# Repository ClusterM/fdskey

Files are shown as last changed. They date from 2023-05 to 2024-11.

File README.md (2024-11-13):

# FDSKey
An open-source, low-cost, and easy-to-build Famicom Disk System drive emulator featuring a sleek OLED display.





How you can use it:
* You can run Famicom Disk System disk images from a microSD card 
* You can dump disks using a physical FDS drive without additional hardware/cables
* You can write disks using a physical FDS drive without additional hardware/cables

Requirements:
* Famicom
* Famicom Disk System RAM adaptor
* microSD card

## How to build it
You'll need a few low-cost components.

### Circuit diagram
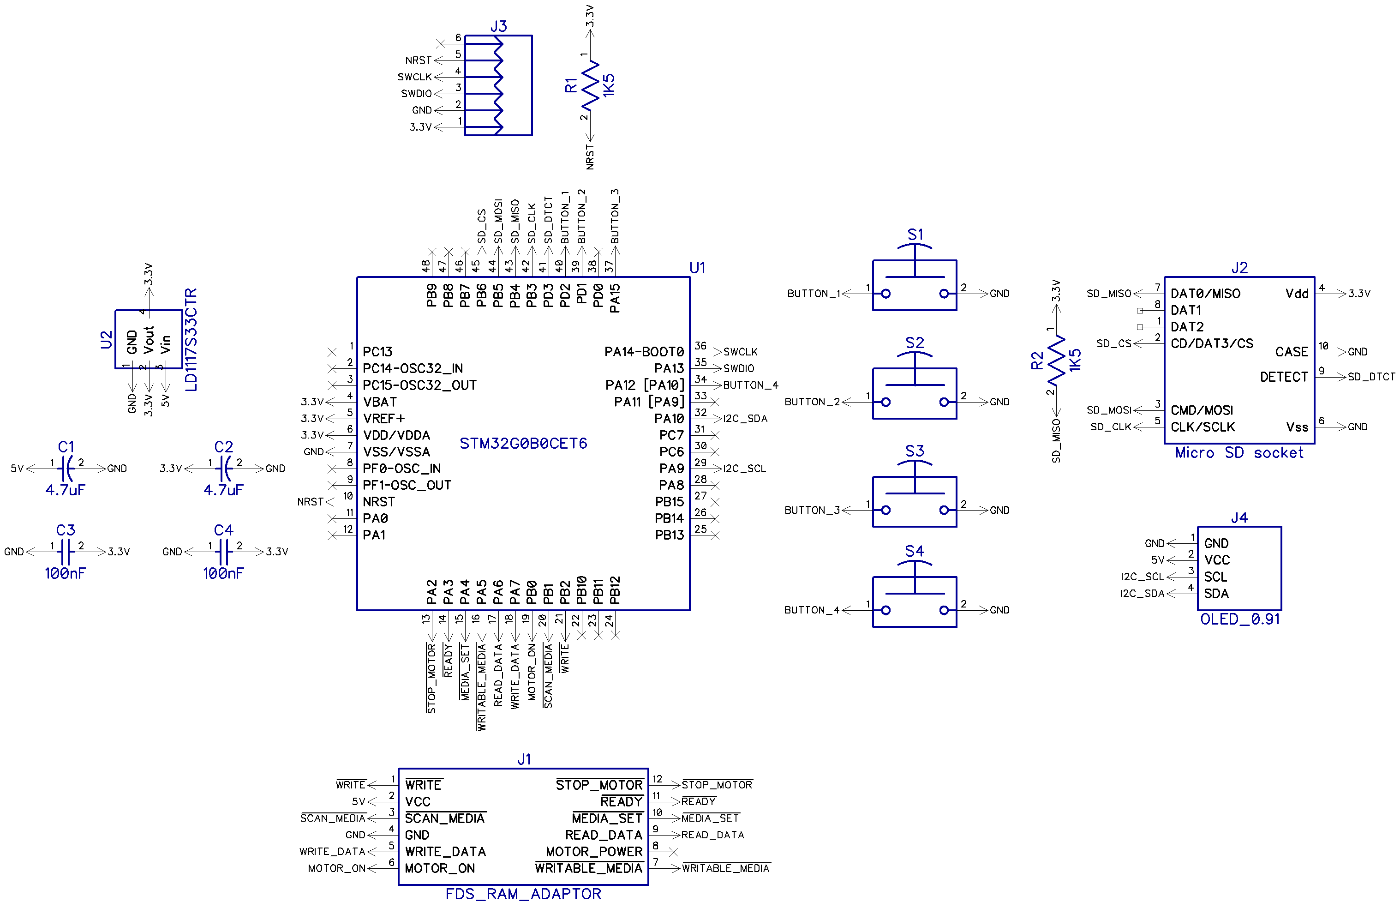
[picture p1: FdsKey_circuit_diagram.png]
Сircuit diagram


### Bill of materials
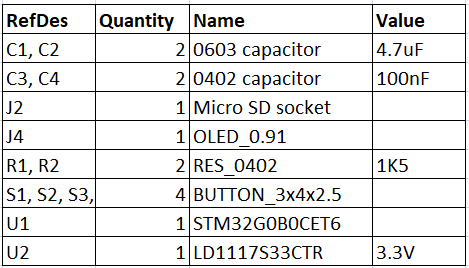
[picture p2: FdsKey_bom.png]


### Components
1. **PCB**



The PCB is designed in the [DipTrace](https://diptrace.com/) software.

You can have it produced at any PCB factory (e.g. [jlcpcb.com](https://jlcpcb.com) or [PCBWay](https://pcbway.com/)) using [gerber files](PCB_gerbers). PCB properties:
* PCB thickness: 1.6mm
* Gold fingers are recommended

2. **STM32G0B0CET (or any STM32G0B0CETxxx) microcontroller**

STM32G0B0CET

You can easily find it on [mouser.com](https://www.mouser.com/c/?q=STM32G0B0CET) or [taobao.com](https://s.taobao.com/search?q=STM32G0B0CET).

3. **OLED display module**

OLED display

OLED display

It's a very popular OLED display, search for **SSD1306 0.91-inch OLED 128x32 4-pin** on [aliexpress.com](https://aliexpress.com), [ebay.com](https://ebay.com), [amazon.com](https://amazon.com) or [taobao.com](https://taobao.com). These displays are available in different colors: blue, white and yellow, you can select the one you prefer.

Solder it like this:



It's recommended to put something soft under the display on the right side.

**WARNING**: some unscrupulous sellers may sell you used, burned-in displays.

4. **microSD card socket (push-push, 8-pin + card detect pin = 9-pin)**

microSD card socket

microSD card socket

It's a very popular push-push socket, they can be found on [aliexpress.com](https://aliexpdress.com). Also, you can search for **112J-TDAR-R01** model but there are many compatible models with other names. You can always modify the PCB to accommodate a different socket model.

5. **LD1117S33 stabilizer**

LD1117S33

You can buy it in any electronic components store.

6. **Four SMD buttons**

SMD button

Search for **3X4X2.5H SMD** buttons, they can be found on [aliexpress.com](https://aliexpress.com), [ebay.com](https://ebay.com), [amazon.com](https://amazon.com) or [taobao.com](https://taobao.com). You can also search for **434133025816** model on [mouser.com](https://www.mouser.com/c/?q=STM32G0B0CET).

7. **Resistors and capacitors**

Capacitor

You will need only a few of them:
* C1, C2 - two 4.7uF ceramic capacitors, 0603 size (higher values are not recommended)
* C3, C4 - two 100nF ceramic capacitors, 0402 size (0603 will be fine too)
* R1, R2 - two 1.5K resistors, 0402 size (0603 will be fine too), actually you can also use any values from 1K to 10K

You can buy them in any electronic components store.

8. **Plastic case**

Case

You can print plastic case with a 3D printer. You can find .stl files in the [case_3d_models](case_3d_models) directory. There are two types of models:
* [For FDM 3D printers](case_3d_models/fdm) - can be printed on a affordable home 3D printer, the bottom and top parts of the case must be glued together
* [For MJF 3D printers](case_3d_models/mjf) (recommended) - for industrial 3D printing, you can order it from a manufacturing service (e.g. [jlcpcb.com](https://jlcpcb.com)), this version features latches



What does it look like when everything is assembled:


## Flashing the firmware
There are five TH pads (actually 6 but 1 is unused) on the PCB to connect a ST-Link (or clone) programmer: GND, VCC, SWD, SWCLK, and NRST. Use [**STM32CubeProg**](https://www.st.com/en/development-tools/stm32cubeprog.html) software (Win/Linux/Mac) to write the bootloader and the firmware. Old **STM32 ST-LINK Utility** will not work, it's deprecated.

First, you need to write the bootloader - **bootloader.bin** file. Use a programmer and write it to the **0x08000000** address (start of the flash memory, default address).

Then you can put the main firmware file - **FdsKey.bin** on your SD card (FAT/FAT32/exFAT formatted) and hold all four buttons on power-on, e.g. connect FDSKey to RAM adaptor, hold buttons and turn a Famicom on. You can use the same method to update the main firmware in the future without additional hardware. You can also use a programmer and write it to the **0x08020000** address.

You can write the bootloader and the firmware at once using the STM32CubeProg CLI tool:

`STM32_Programmer_CLI.exe -c port=SWD --erase all --download bootloader.bin 0x08000000 --download fdskey.bin 0x08020000`

After the first boot, press and hold the **left** button on the main menu screen for 3 seconds to access the service menu. There, you can select the OLED display controller type (change it if the display shows a corrupted image in "lefty mode") and check some system information.

## Device usage
Format a microSD card to FAT/FAT32/exFAT and put some .fds files on it. Insert a microSD card into a FDSKey, insert a FDSKey into a RAM Adaptor's cable instead of a physical disk drive and turn on a Famicom. You can hot plug a FDSKey when Famicom is already on too, it's ok.

Now you can navigate through the FDSKey interface using the buttons. **Left** button usually means **back**, **right** button usually means **OK** and **up**/**down** are used to select something (file, disk side, etc.) Also, you can long press the **left** button in the file browser to directly return to the main menu from a subfolder, and long press the **right** button to open the file properties menu.

FDSKey - interface flowchart

Oops, too complicated :( Let's try again...

GUI

Much better.

**WARNING**: when a game writes some data to a virtual disk (i.e., saves game progress) don't turn off your Famicom power until the updated ROM has been saved to the SD card. Wait a second for it or eject a virtual disk (**left** button). A **saving** message will be displayed, do not turn off power while this message is visible.

### Settings menu
Use **up**/**down** buttons to select a setting and **left**/**right** to change it. Setting descriptions:
* **Rewind speed**: you can select a drive operation speed as either **original** (very slow, like on a physical FDS drive, for the nostalgic ones), **fast** (where the rewind time is reduced but the virtual head position is not altered), or **turbo** (the fastest possible mode, instant head rewind).
* **Remember state**: you can select a power-on state between **none** (always start from the main menu), **browser** (open browser and select last file if browser was opened before power off), and **ROM** (start first side of the last started game emulation if ROM emulation was active before power off).
* **Saves** (since v1.1): you can select how to save game progress as either **overwrite** (just overwrite the original .fds file), **backup+overwrite** (just overwrite the original .fds file but make backup to .fds.bak file first), or **like EverDrive** (EverDrive-compatible saves format).
* **Hide non .fds files**: hide files with non .fds extension in the file browser.
* **Hide .fds extensions**: hide .fds extension in the file browser.
* **Hide hidden files**: hide hidden files and directories in the file browser.
* **Brightness**: screen brightness from 0 to 10.
* **Invert screen**: draw black on white instead of white on black.
* **Lefty mode**: rotate screen image on 180 degrees and flip buttons.
* **Screen off after**: time before automatic screen off if there is no any action (button presses, drive activity), it's recommended to use this feature to prevent OLED screen burn-in.
* **[ Save and return ]**: press **left** or **right** button on this item to return to the main menu.

### Service menu ###
You can access the service menu by holding the **left** button on the main menu screen for 3 seconds. This menu is mainly meant for developers or advanced users. There is a lot of system information and several options/functions:
* **OLED controller**: try to change it in case if "lefty mode" is not working correctly.
* **[ Format SD card ]**: use it if you want to make low-level format of your SD card. Use it with caution as you will lose all your data! Make sure to backup your data first.
* **[ Update bootloader ]**: update bootloader firmware. You need to put both **bootloader.bin** and **bootloader.bin.md5** files in the root of your SD card. Use it with caution! In case of failure (power loss during update) you will brick the device.
* **[ Save and return ]**: press **left** or **right** button on this item to return to the main menu.

## Reading and writing disks

### How to dump a physical disk to a file
You can use [DupliFDS](https://github.com/ClusterM/duplifds) to copy a physical disk to a virtual one, simply create an empty ROM. There is **Create blank disk** item in the main menu for it.
1. Put the DupliFDS ROM on the SD card.
2. Select and load the DupliFDS ROM on your SD card just like you would do with any other ROM.
3. Return to the main menu and select **Create blank disk**.
4. Enter filename for the new ROM, trailing spaces will be trimmed.
5. When DupliFDS requests a source disk, disconnect FDSKey from a RAM adaptor and connect a physical FDS drive with a game disk.
6. When DupliFDS requests a target disk, disconnect a physical drive, connect a FDSKey and select the ROM created in steps 3-4.
7. Repeat steps 5-6 until the copy operation is completed.

### How to write to a physical disk from a file
This is a reverse operation of dumping: you can use [DupliFDS](https://github.com/ClusterM/duplifds) to copy a virtual disk to a physical one. Please note that **you need to remove the copy protection from your physical drive** if it has any. In most cases, it's not such a difficult process.
1. Put the DupliFDS ROM on the SD card.
2. Select and load the DupliFDS ROM on your SD card just like you would do with any other ROM.
3. When DupliFDS requests a source disk, select the source ROM/side.
4. When DupliFDS requests a target disk, disconnect FDSKey from a RAM adaptor and connect a physical FDS drive with a blank disk.
5. Disconnect a physical FDS drive and connect the FDSKey.
6. Repeat steps 3, 4, and 5 until the copy operation is completed.

## Firmware updates
You can always download the latest version at https://github.com/ClusterM/fdskey/releases.

Also, you can download automatic interim builds at http://clusterm.github.io/fdskey/.

Remember, you can update the firmware by putting **FdsKey.bin** on your SD card and holding all four buttons on power-on.

## Twin Famicom compatibility
You can use FDSKey with Twin Famicom too. But you need a special cable. It's easy to make one.



It has a simple 12x1 dupont connector on the one side, you need to connect it to Twin Famicom's **Port C** on the back-bottom side (instead of the original cable).

Unfortunately, there is a non-standard connector on the other side of the cable. But you can use a SFC/SNES/N64/NGC AV connector:



You can find it on [aliexpress.com](https://aliexpress.com). But you need to cut a "key" - piece of plastic on this connector, or just use the FDSKey without a case.

Connection diagram:
```
           Twin Famicom Port C                   Connector for FDSKey
       (looking at rear of console)          (looking from FDSKey's side)
█████████████████████████████████████████  ████████████████████████████████
█████████████████████████████████████████  ████████████████████████████████
██                                     ██  ███  1   3   5   7   9   11  ███
██ 8  6  2  4  1  3  5  7  9  11 12 10 ██  ███  2   4   6   8   10  12  ███
█████████████████████████████████████████  \██████████████████████████████/
█████████████████████████████████████████   \████████████████████████████/

Pin meanings
+----+---+-----------------------+
| 1  | O | /write                |
| 2  | O | VCC (+5VDC)           |
| 3  | O | /scan media           |
| 4  | O | VEE (ground)          |
| 5  | O | Write data            |
| 6  | I | Motor on/battery good |
| 7  | I | /writable media       |
| 8  | - | ---                   |
| 9  | I | Read data             |
| 10 | I | /media set            |
| 11 | I | /ready                |
| 12 | O | /stop motor           |
+----+---------------------------+
```

You **must** pull-up **write data** line to **VCC** via resistor (5K-20K) if you want to save game progress, because Twin Famicom has no pull-up resistors inside it.



Also, it's recommended to pull-up **/media set** pin to **VCC** too if you want to hot plug the FDSKey. And don't forget to upgrade the FDSKey firmware to at least **v1.3**.

## Donate
* [Buy Me A Coffee](https://www.buymeacoffee.com/cluster)
* [Donation Alerts](https://www.donationalerts.com/r/clustermeerkat)
* [Boosty](https://boosty.to/cluster)

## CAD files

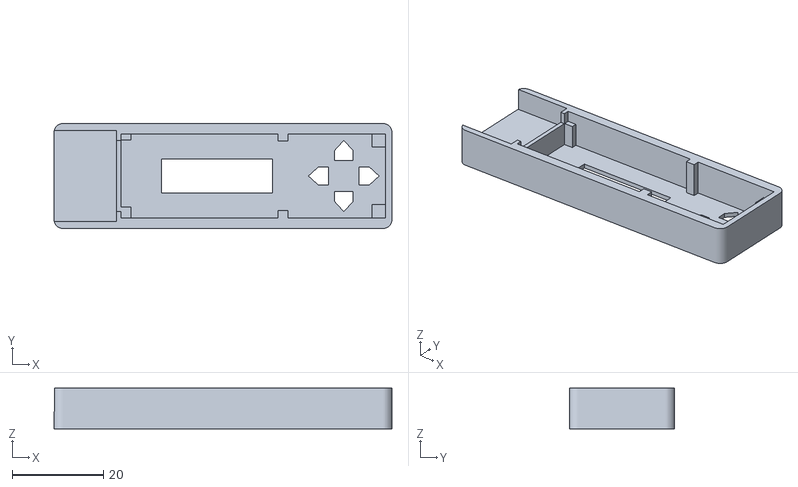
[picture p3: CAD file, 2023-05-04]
case_3d_models/fdm/top.stl
74.0 x 23.0 x 8.90

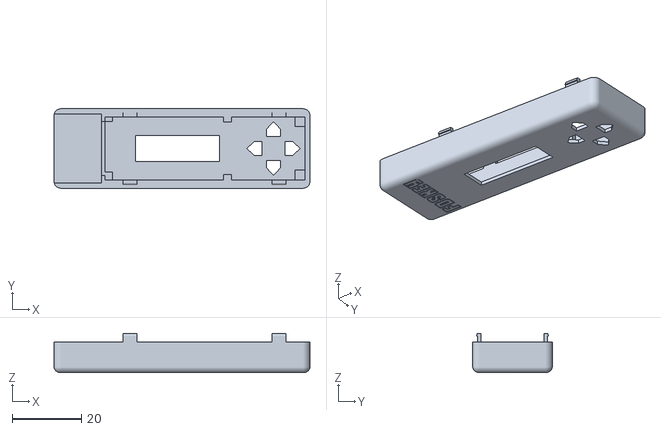
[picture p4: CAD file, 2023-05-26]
case_3d_models/mjf/top.stl
74.0 x 23.0 x 11.4

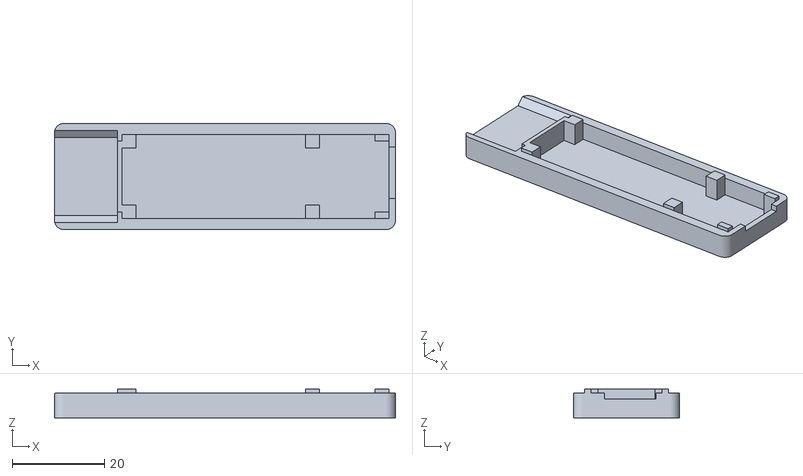
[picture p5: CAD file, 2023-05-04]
case_3d_models/fdm/bottom.stl
74.0 x 23.0 x 6.21

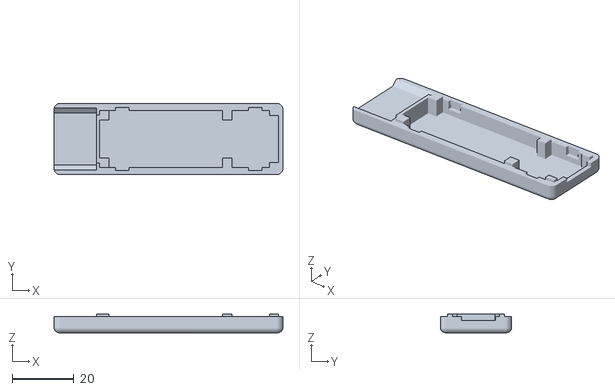
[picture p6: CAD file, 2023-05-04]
case_3d_models/mjf/bottom.stl
74.0 x 23.0 x 6.10

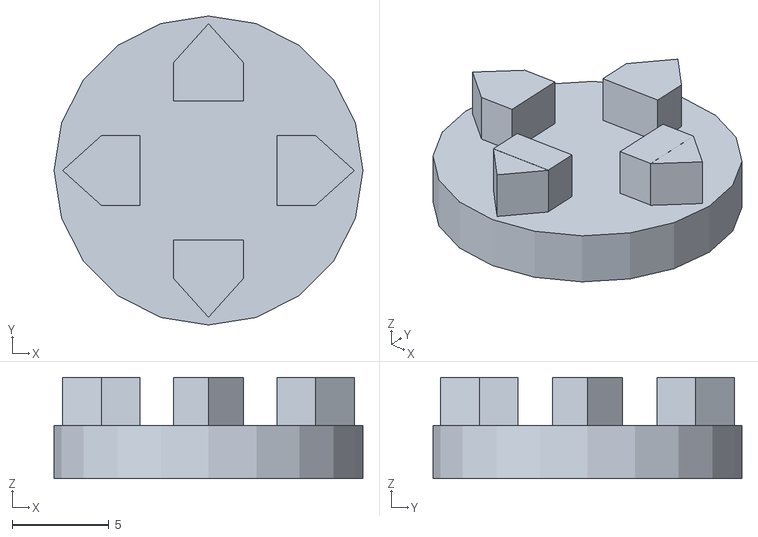
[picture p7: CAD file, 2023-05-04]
case_3d_models/fdm/buttons.stl
16.0 x 16.0 x 5.25

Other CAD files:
case_3d_models/mjf/buttons.stl

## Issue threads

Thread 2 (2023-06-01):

Broken BOM link

breyell, 2023-06-01:
Links to file in repo that doesn't exist

ClusterM, 2023-06-01:
Oops. I renamed the files but forgot to change links. Fixed. Thank you!

Closed 2023-06-01.

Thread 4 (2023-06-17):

How to flash the bootloader

donly, 2023-06-17:
Hi, there!
I read the instructions from https://github.com/ClusterM/fdskey#flashing-the-firmware, but still get stuck in connect to target:

```
Can not connect to target!
If you're trying to connect to an STM32W1xx device, please select Normal or HotPlug mode from Target->Settings menu.
If you're trying to connect to a low frequency application , please select a lower SWD Frequency mode from Target->Settings menu.
```

donly, 2023-06-17:
When using this setting, it can be connected, but it shows an unknown device, as shown in the figure
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

What kind of `Mode` and `Reset Mode` should be use.

ClusterM, 2023-06-21:
Sorry for the slow reply. Double check the connections and make sure the UC is not broken. Also? check the power. Reset mode depends on your programmer. If it has a NRST connection - use hardware reset.

donly, 2023-06-22:
Thank you ClusterM. As I'm a newbie and don't know how to use it, it's been solved now.

partlyhuman, 2023-07-27:
> Thank you ClusterM. As I'm a newbie and don't know how to use it, it's been solved now.

@donly, I too am new to STLink, I've got a clone ST-Link V2 and using the ST-Link utility. Can you elaborate for other newbies what you did to get it working?

My issues thus far:
* Only works in Mode = Hot Plug, otherwise fails to connect
* Seems to hang up if Hardware reset mode is used and NRST are connected
* "Read out protection is activated" trying to erase or program the STM32
* "the elf loader file is not accessible" when trying to program the STM32

Thank you in advance for any advice you can share! :)

donly, 2023-07-27:
Maybe your clone ST-Link doesn’t support this chip, can you try another flash tool

partlyhuman, 2023-07-27:
> Maybe your clone ST-Link doesn’t support this chip, can you try another flash tool

It's quite possible the clone ST-Link V2 usb programmer is the issue. I don't currently have any alternative... is that what your issue was?

donly, 2023-07-27:
Yes, just forget this programmer..

Closed 2023-06-20.

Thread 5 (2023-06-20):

Can work with antother STM32 microcontroler?

eduardokenj, 2023-06-20:
When i search for stm32g0b0cet6 to buy form China, i have a shortage of this chip... Can you or is easy for me, recompile for another STM32 chip where more available? (And yes if i import from USA the import tax is too high for me)
TKS

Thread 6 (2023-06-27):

No space for beveling on the PCB

rfmerrill, 2023-06-27:
Different PCB manufacturers likely have different requirements, but for people who want to file bevel by hand on the PCB, it would be nice if there were a bigger gap after the contact fingers before the edge. As it is, it's hard to file a bevel without hitting the contacts, potentially making them more vulnerable to corrosion.

I don't want to push a lot of work on you, I just don't have Diptrace to do it myself. Maybe I can edit the gerber files directly?

ClusterM, 2023-06-30:
Hello. How big should the gap be? I'll edit it by myself, thank you.

rfmerrill, 2023-06-30:
PCBWay says minimum 1mm but for hand-beveling 2mm would probably be better.

Also you likely also want chamfer cuts at the sides but that could also be done by hand.

ClusterM, 2023-07-18:
Added 1.5mm.

Closed 2023-07-20.

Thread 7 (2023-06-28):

Error :(  SD card not ready on small SD cards

donly, 2023-06-28:
I bought some sd cards with different capacities to test, and found that the cards with a capacity below 4g would have this error.
```
Error :(
SD card not ready
```

PASSED: 4g, 8g, 16g, 32g, 64g
FAILED: 1g, 128m

Notes: All tests using the same file system format FAT32. 1g and 128m sd cards are low speed without C10.

ClusterM, 2023-07-20:
I'm still waiting for delivery. But can you try interim version? http://clusterm.github.io/fdskey/

donly, 2023-07-21:
Thank you for the updated, I tried the latest build, now it works with 1g SD card, but 128m still gets FAILED.

ClusterM, 2023-07-21:
> Thank you for the updated, I tried the latest build, now it works with 1g SD card, but 128m still gets FAILED.
>

I'll wait for delivery with SD cards, thank you!

ClusterM, 2023-07-24:
Please try again: http://clusterm.github.io/fdskey/

donly, 2023-07-25:
> Please try again: http://clusterm.github.io/fdskey/

FAILED on 128m.

It seems to take longer before the OLED lights.

ClusterM, 2023-07-29:
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

Try again please.

donly, 2023-07-29:
About 1.5 seconds the oled turn on and show the same error.
I Updated the latest `fdskey.bin` from http://clusterm.github.io/fdskey/ using a 64gb card, then insert a 128m card with fat32 of file system.

ClusterM, 2023-07-29:
Weird. Yes, i received SD cards from Ali.

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

And every card works fine for me. I'll try to add some debug info to the error message.

ClusterM, 2023-07-29:
Please try the current version and tell me the error code.

donly, 2023-07-30:
I tested 5 128m cards, all of them have error code `2`, except one error code is `7`.
Additional tests with different file formats for this card, the error code is still `7`, and only this card has 1.5 seconds delay to light on.
Every cards works well on windows, maybe it's the quality of the cards, after all, it's a cheap cards..
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

ClusterM, 2023-07-30:
Error 2 occurs at the very early stage, like SD card is not connected at all. Weird :( I have no idea.
In any case, I wouldn't recommend using these cheap SD cards because they can die and lose your save files.

ClusterM, 2023-07-30:
Maybe these SD cards can't work in SPI mode for some reason? PC card readers usually do not work via SPI.

donly, 2023-07-30:
Okay, I will use good branded cards. I'm very happy that the card you purchased is OK.
Anyway, thank you very much for your effort.

Closed 2023-07-30.

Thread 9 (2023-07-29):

Error: 02

williamgentry12, 2023-07-29:
If i get the following error code: 02

Does this mean something is faulty with the FDSKey hardware, maybe broken solder joint on the STM32 chip?

Err. 02 = No disk power supply — batteries and/or AC adaptor.

ClusterM, 2023-07-29:
Hi! Can you try interim firmware version? http://clusterm.github.io/fdskey/
Put fdskey.bin file on a microSD card and hold all four buttons during power-on to update the firmware.
If problem persists it's hardware problem on MOTOR_ON pin (shorted to ground?).

williamgentry12, 2023-07-29:
Thank you, I will try :)

kingtreelo, 2023-07-30:
i was having the exact same issue and this has fixed the issue for me

williamgentry12, 2023-07-30:
works for me too

ClusterM, 2023-07-30:
I'll add this fix to release. Thank you for bugreport!

kingtreelo, 2023-08-01:
this issue seems to have come back on my device, tried flashing it again and still getting the same error

ClusterM, 2023-08-01:
> this issue seems to have come back on my device, tried flashing it again and still getting the same error

:( Please try this firmware: https://cluster.wtf/temp/FdsKey.bin

But it's not normal. Looks like some hardware problem on line MOTOR_ON.

ClusterM, 2023-08-03:
Any news?

kingtreelo, 2023-08-03:
Just tested on 2 of my Famicoms, all looks good so far, will report back once it has been powered off a while, i'll update it in a few hours

kingtreelo, 2023-08-04:
Looking good still today

ClusterM, 2023-08-05:
Great, I'll include this in the next version.

Closed 2023-08-05.

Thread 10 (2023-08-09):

CPL File

Radeon91, 2023-08-09:
Please could you update CPL file?
I want to make it but my welding skills are not very good, I would like to order them already welded.

Thanks

ClusterM, 2023-08-09:
What is CPL file? 😮

ClusterM, 2023-08-09:
Try this: [fdskey.csv](https://github.com/ClusterM/fdskey/files/12302885/fdskey.csv)
Also, you can buy already assembled device on AliExpress: https://www.aliexpress.us/item/3256805697532063.html
And other sites.

Closed 2023-08-16.

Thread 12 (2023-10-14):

Programming Issue Using ST-Link-V2 - Read Out Protection Error.

PercyRosasR, 2023-10-14:
First of all, thanks for all the effort in this project, thanks to ClusterM for creating this.

I have made 2 unids following all the instructions on the FdsKey principal page, I am having some issues with the connection and programming the STM32G0B0CET6 chip.

I use the ST-Link-V2 Clone, with STM32-ST-Link-Utility, this is because is the only way I had to connect the board via stlink.

1.- Using STM32-ST-Link Utility

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

23:41:12 : ST-LINK SN : 700039000F0000315151524E
23:41:12 : V2J42S7
23:41:12 : Connected via SWD.
23:41:12 : SWD Frequency = 4,0 MHz.
23:41:12 : Connection mode : HotPlug.
23:41:12 : Debug in Low Power mode enabled.
23:41:12 : Device ID:0x467
23:41:12 : Device family :Unknown device

My first question is, if this Device family information is correct?

2.- When I try to program the chip using the bootloader bin fie, this issue happens:

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

Pressing the ok button , the next error appears.

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

Do you have any clue or advice to solve this problem?

I have already try to disable the Read out protection, but I got this issue after applying.

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

3.- Also want to explain, why I'm not using the STM32Cubeprogrammer.

This is because when I connect my stlink32 in the combo box Serial Number, i got the letter P in both of my boards.

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

and when I change the Shared combo to Enable, I got this, and I am not able to connect the device in any way.
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

I hope you can help me with this issue.

Thanks for all in advance and greetings from Peru.

ClusterM, 2023-10-14:
Hi! The STM32-ST-Link Utility will not work :( It doesn't recognize this microcontroller (it's a new model). I don't know why STM32CubeProgrammer has such weird behavior, but you need to use it. Please try the CLI version:

```
STM32_Programmer_CLI.exe -c port=SWD --erase all --download bootloader.bin 0x08000000 --download fdskey.bin 0x08020000
```

PercyRosasR, 2023-10-14:
Hi Alexey,

you are completely right. The old stlink software does not allow me to complete the programming(connects but gives the lock error).

The cube software has a different problem.

The solution you gave is the correct one, by cmd and the command I was able to program my chips.

Now I'm having a different issue I will open a new topic, to close this one.

Thanks in advance for your help.

partlyhuman, 2024-07-23:
Thank you! Issues flashing the STM32 aborted my efforts to build the FDSkey last year. This new instruction worked perfectly for me the first time.

FYI if you're on MacOS, you can find the CLI at
```
/Applications/STMicroelectronics/STM32Cube/STM32CubeProgrammer/STM32CubeProgrammer.app/Contents/MacOs/bin/STM32_Programmer_CLI
```
assuming the default installation.

Closed 2023-10-14.

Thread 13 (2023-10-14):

No SD Card Issue!

PercyRosasR, 2023-10-14:
Hello Alexey and everyone.

I am having the next issue with my unit.

When I turn my fdskey without a micro sd card I got this message.
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

When I insert the micro sd, the screen turns black without response. It looks like it's turned off or something different happened.

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

If I start the console with the micro sd inserted, the same problem shows, a black screen.

I have already tried with 2 micro sd, one 2gb Samsung, and 16gb sandisk.

I am adding a YouTube video of the problem.

https://youtube.com/shorts/ha5OHcCc-NU?feature=share

-------------------------------------------------------------------------------------------

Also I tried to update by pressing the four buttons but it get stuck with the "Please Wait" message:

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

I hope you can help me solve this issue.

*I had reweld the sd card holder pins and got the same issue.

Thanks in advance.

ClusterM, 2023-10-15:
Seems like the card init process has not even started. Please check the card detect line/pin. Sometimes the card detect mechanism can also be broken. Try to short the card detect line to the ground. The card socket must connect it to the ground when an SD card is inserted.

PercyRosasR, 2023-10-15:
Hi Alexey, good morning and greetings from Peru.

I shorted the cd line to the ground and I got a black screen.

I have already made 3 of the fdskey boards to test and all those have the same behavior.

What else could it be? Do you think it might be faulty micro sd card sockets?

Let me know if you need more detail, I followed all the instructions, but I don't know if could be a bad capacitor or resistor.

Thanks in advance for your help.

ClusterM, 2023-10-16:
Weird. I have no idea.

PercyRosasR, 2023-10-16:
After doing some additional tests, I was checking the voltages in the board.

And I was having less than 3.3v, in some cases 2.6v. Then I realized that I had a mod to connect USB C to give power to the console.

So I connected the regular 10v adapter and my unit came alive, so was a mistake from my last mode.
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

I will try to fix that, but the system is pretty good and works properly.

Thanks, Alexey for your help.

This device is pretty awesome.

ClusterM, 2023-10-16:
You are welcome :)

Closed 2023-10-16.

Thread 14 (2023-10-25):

ROM that bypassed KYODAKU becomes Invalid ROM

Hidetyo, 2023-10-25:
Hello,

An "Invalid ROM" error occurs in the ROM of a homebrew game that has been KYODAKU bypassed.
This ROM works correctly on the emulator.

This problem occurred with the sample ROM at the URL below:
https://github.com/bbbradsmith/NES-ca65-example/tree/fds

ClusterM, 2023-10-25:
Hello.
That's because file amount value is greater than actual file amount. I need to add some special mode for it, i think...

ClusterM, 2023-10-25:
Oh... I already fixed it, lol. Are you sure that you tried the current interim build? It should be 78424a5.

Hidetyo, 2023-10-26:
Oops, I only tried Bootloder.
I updated the main firmware and it works correctly.

My apologies! And thank you very much.

Hidetyo, 2023-10-26:
But when I use it with Duplifds(v1.1 and interim builds), I get an Inval ID Block error...

ClusterM, 2023-10-26:
> But when I use it with Duplifds(v1.1 and interim builds), I get an Inval ID Block error...

I know, I'll try to add some special mode to DupliFDS.

kazueda, 2024-02-23:
Hello from Japan.
When I am trying to bott a lunix.fds of the lng-fds project, your firmware built from a current github cloned files shows "invaild rom."
Are there some advice to overcome this situation?
Sincerely yours,

PS
Url of lng-fds in github.com
https://github.com/decrazyo/lng-fds

kazueda, 2024-02-23:
Some Progress.
File size of linux.fds is 14 kB.  So I made  65516 bytes file from the linux.fds.
But when I proceed to load shell program, "Error, Wrong block CRC" was displayed.

ClusterM, 2024-02-23:
@kazueda Hi! I'll check, but a bit later. Can you create a new issue about it? So i will not forget.

kazueda, 2024-02-23:
@ClusterM  I will set new issue.

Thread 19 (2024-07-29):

How to transmit data over a single line？

shangwuhen, 2024-07-29:
Hi,
  According to FDS hardware  ,it reads and writes data through only one wire,it converts one byte of parallel data into 1-bit serial data during each transmission(It looks like this),
  I want to create a cloned version of an FDS RAM adapter using CPLD,I searched for relevant information online,but there was no result. I also reviewed the source code of simulators such as fceux and mesen,but the simulator ignored the detailed information of the hardware part,so I would like to know more detailed information about this section,Can you help me provide more detailed information
  (The source code of the fdskey project contains relevant information, but I don't quite understand it,It seems that DMA and Timer were used)
  Thank you.

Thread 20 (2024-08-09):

Unable to load any dump

LucentW, 2024-08-09:
Hey,
I got ahold of one of the prebuilt FDSKey PCBs off AliExpress, it turns on regularly, I am able to select a dump off the SD card, it signals correctly to the RAM adapter a disk was inserted, but it indefinitely loops around the disk, the FDS BIOS staying stuck on the "now loading" screen (never passing KYODAKU/no black screen before the copyright notice).

I tried already updating to the interim build (both bootloader and software), changing microSD card, using different RAM adapters (both work perfectly fine with my FDS drive) and reflowing all components. I also checked the two resistors on the board, since testing caps while in circuit is not really a good test, and they respect the BOM (both 1.5k).

What could be the issue? Which connections should I check?

Thank you very much in advance ;-)

LucentW, 2024-08-12:
Figured out that the via for READ_DATA was open potentially due to a PCB manufacturing error, I just ordered another prebuilt from another seller and called it a day. Sorry for the hassle :)

ClusterM, 2024-08-12:
Hi. Sorry for not so fast answer. Ok :)

Closed 2024-08-12.

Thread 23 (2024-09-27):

FDSkey gives me Error 03 while attempting to save

Cyrus331, 2024-09-27:
When FDSKEY plays some games that need to be archived, a 003 error message will appear. Other games that do not require archives can be played normally. Is it a RAM problem, a FDSKEY problem, or an SD card problem?

ClusterM, 2024-09-27:
Hi! What you mean by "archived"?

donly, 2024-09-27:
I have tried using an SD card to play a game that requires a save file and it results in error 07.
Can you try with another SD card

Cyrus331, 2024-09-27:
> Hi! What you mean by "archived"?

It means this game has a save function，

Nazo no Murasamejou (1986)(Nintendo)(J)[tr En].fds

Metroid (v1.02) (1986)(Nintendo)(J)[h3].fds
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

kalm-traveler, 2025-08-17:
I get this when trying to load specific games as well - just got my FDS RAM adapter today and could not get Akumajo Dracula (the first Castlevania) or Metroid to save (or in Metroid's case to even load the game after trying to create a save file). ERR 03 as well. Tried the same disk images on an Everdrive and no issues. Is there a setting on the FDSKey to 'allow' writing to disk?

donly, 2025-08-19:
Where did you use it?  @kalm-traveler

> You must pull-up write data line to VCC via resistor (5K-20K) if you want to save game progress, because Twin Famicom has no pull-up resistors inside it.

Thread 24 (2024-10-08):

ERR . 22

Inzocknito, 2024-10-08:
Hi, I purchased the FDSKEY twice from aliexpress. I have "Disk Trouble ERR. 22" on both. I've tested it on a normal Famicom, a NewFamicom board and with an AVS. The same problem on every console. I've also tried two different HVC-23s... The same problem always occurs. Do you have a solution to the problem?

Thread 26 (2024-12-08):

Unable to load "Tile Editor (Newer) (Sunsoft)" - disk capacity mismatch?

TakuikaNinja, 2024-12-08:
Trying to load this development tool on the FDSKey results in error 25. The display shows the disk as being filled completely, despite the fact that all the file blocks fit well within a single-sided .fds file. I'm wondering if there's an inaccuracy regarding the gap size between files (mainly block types 3 & 4). Editing the file amount to 3 (the minimum required to boot the tool) works fine for now but it's quite annoying that the included graphics files cannot be loaded at the moment.

The Sunsoft Dev Disks which contain the program in question will not be linked here. The archived disks aren't hard to find.

TakuikaNinja, 2025-02-25:
Update: this might apply to more unlicensed/unofficial disks than I initially thought. I just tried "The Golf - Bishoujo Classic" and it fails to load the B side for seemingly the same reason. I'm guessing that these disks use/expect a smaller gap size compared to licensed disks.

TakuikaNinja, 2025-02-25:
I've had a look at some resources regarding the gap sizes. The NESdev wiki article for the [disk format](https://www.nesdev.org/wiki/FDS_disk_format#Gaps) appears to have had these numbers for the gap sizes since 2012 (originally present on the [FDS hardware article](https://www.nesdev.org/w/index.php?title=Family_Computer_Disk_System&type=revision&diff=2933&oldid=2930) before being moved):

> - Before the start of the disc : At least 26150 bits, 28300 typical.
> - Gap between blocks : At least 480 bits, 976 bits typical.

Meanwhile, the [technical reference](https://nesdev.org/FDS%20technical%20reference.txt) by Brad Taylor from 2004 lists the following:
> - The length of the first GAP period present on typical FDS disks (relative to the instant the disk drive's "-ready" signal is activated) is about 40000 bits, after which the first block start mark (indicating the beginning of the first file) will appear.

> - Writing to the disk does not occur in sync with the existing data on the disk. Where a write period starts and ends is bad news because it creates a gap between pulses almost always of an invalid length. This would lead to the RAM adaptor misinterpreting the data, causing errors. To overcome this, the RAM adaptor always ignores the first 488 bits (aprox.) to follow after the immediate end of any file. This period allows the RAM adaptor (or the game rather) an oppertunity to make the switch from reading from the disk to writing or vice-versa.

> - The typical GAP period size used between files on FDS disks is roughly 976 bits (this includes the bits that are ignored by the RAM adaptor).

So 480~488 bits may need to be considered as the minimum gap size for the contents of these disks to fit onto a disk side?

I suppose this has only become an issue now because the FDSKey needs to read a .fds format file (which lacks gaps/CRCs) and provide an accurate data stream including gaps/CRCs, while somehow keeping track of the disk capacity in case a disk image actually managed to overfill a disk side. For reference, [VirtuaQD](http://www.2a03.jp/~norix/virtuaqd/index.html) (a generic QD drive emulator) and its disk image conversion tools use an MFM encoded format. It treats a complete disk side (excluding the external header) as 80KiB on the FDS. I can't recall any other cases of the "true" capacity being measured or referenced.

TakuikaNinja, 2025-03-12:
I have example files which reproduce the issue, based on a WIP version of a disk capacity test program I've been writing:
- `disk-capacity-tests_cfff.fds` has the final file at $CFFF bytes long, which FDSKey claims as fitting within a disk side.
- `disk-capacity-tests_d000.fds` has the final file at $D000 bytes long, which FDSKey claims as not fitting within a disk side.
[disk-capacity-tests_wip.zip](https://github.com/user-attachments/files/19201985/disk-capacity-tests_wip.zip)

They don't do anything special upon loading - [FDS Disk Lister](https://www.chrismcovell.com/fds-lister.html) can be used to list the disk contents if needed. Both versions have their contents fit well within a single-sided .fds file (~7398 bytes free).

TakuikaNinja, 2025-03-17:
I really should have said this sooner - If the loaded disk side is full, the FDSKey seems to omit the file data which exceeds the limit instead of truncating it like on a real disk. The BIOS is capable of detecting when files prematurely end during reads/writes.

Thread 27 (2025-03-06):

Copy protection is erroneously triggered on certain unlicensed disks

TakuikaNinja, 2025-03-06:
There are a handful of unlicensed disks which used unusual formats to thwart disk copiers at the time, and it seems that the FDSKey is erroneously triggering them.

- Kosodate Gokko (disk copier) stores its main program _without a file block indicator_ and loads it using the BIOS IRQ handler. (data is prefixed with a $12 byte in the disk image) A Tron-like minigame becomes the only thing accessible if the main program is missing. I've come across this one with puNES before: https://github.com/punesemu/puNES/issues/396
- Quick Hunter (disk copier) utilises low-level disk access routines to load a _file block type of 0_ containing its encrypted main program (data is XORed with $C9). The CRC value of the file block is still checked. A correct load should result in a clean logo screen followed by a prompt to insert a disk to copy.
- Hokusai and Jingorou (graphic editors) store/load their main programs using _fake file header/data blocks_ in a custom format.

Further details in English: https://forums.nesdev.org/viewtopic.php?t=18777

Attempting to load these will get past the BIOS but fail to load any extra data or make proper progress afterwards. What I assume is happening with FDSKey here is that it's expecting all disk images to conform to the format used by the BIOS. The disk capacity visualisation being suspiciously empty for some of these is a likely indicator of this.

I believe the only solution here is to properly present the data as if it were on a real QD. I'm aware that this is likely very difficult to implement on top of #26.

(I assume this also affects [duplifds](https://github.com/ClusterM/duplifds) - not that it's really expected for one to try copying those disks...)

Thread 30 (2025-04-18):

FDSkey won’t load any ROMs

CabbagesCabbages, 2025-04-18:
I formatted my SD card, downloaded the most recent .bin, held the four buttons down to update, all looked good. No .fds ROMs will load, and the loading bar will only fill up 3/4 of the way when selecting a game and won’t move past this. Am I missing something? First timer here, thanks for any help in advance.

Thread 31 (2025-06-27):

Disk flip not recognised by "Neunzehn - 19"

TakuikaNinja, 2025-06-27:
The FDSKey's disk flip fails to be recognised by a particular game: "Neunzehn - 19"
To reproduce it: load the game, press start a few times, then attempt to flip the disk when the side B prompt appears. It currently requires the user to eject the disk, reselect the image after some delay, then pick the new side for it to work.

I looked at the code to see what was causing this behaviour. It turns out that the game waits at least ~512ms (2 calls to Delayms with Y=0) between $4032 polls - unusually long compared to most games.

For reference, Mesen2 applies a fixed 2 second delay between ejecting the disk and inserting a new side. I suggest that the FDSKey either replicate this longer delay, or offer a setting to change the delay between disk flips so the user can choose a shorter delay in scenarios where this matters less.

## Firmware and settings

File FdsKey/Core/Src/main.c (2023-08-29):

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
/* Includes ------------------------------------------------------------------*/
#include "main.h"

/* USER CODE BEGIN Includes */
#include "oled.h"
#include "mainmenu.h"
#include "settings.h"
#include "fdsemu.h"
#include "splash.h"
#include "servicemenu.h"
/* USER CODE END Includes */

I2C_HandleTypeDef hi2c1;

SPI_HandleTypeDef hspi3;

TIM_HandleTypeDef htim1;
TIM_HandleTypeDef htim3;
TIM_HandleTypeDef htim4;
TIM_HandleTypeDef htim17;
DMA_HandleTypeDef hdma_tim3_up;
DMA_HandleTypeDef hdma_tim17_ch1;

void SystemClock_Config(void);
static void MX_GPIO_Init(void);
static void MX_DMA_Init(void);
static void MX_I2C1_Init(void);
static void MX_SPI3_Init(void);
static void MX_TIM3_Init(void);
static void MX_TIM17_Init(void);
static void MX_TIM1_Init(void);
static void MX_TIM4_Init(void);
/* USER CODE BEGIN PFP */

void HAL_GPIO_EXTI_Rising_Callback(uint16_t GPIO_Pin)
{
  switch (GPIO_Pin)
  {
  case FDS_SCAN_MEDIA_Pin:
  case FDS_WRITE_Pin:
    fds_check_pins();
    break;
  case SD_DTCT_Pin:
    show_error_screen("The SD card is ejected", 1);
    break;
  }
}

void HAL_GPIO_EXTI_Falling_Callback(uint16_t GPIO_Pin)
{
  switch (GPIO_Pin)
  {
  case FDS_SCAN_MEDIA_Pin:
  case FDS_WRITE_Pin:
    fds_check_pins();
    break;
  }
}

void HAL_TIM_PeriodElapsedCallback(TIM_HandleTypeDef *htim)
{
  if (htim == &htim1)
    fds_check_pins();
}

void delay_us(uint16_t us)
{
  htim4.Instance->EGR |= TIM_EGR_UG;
  while (htim4.Instance->CNT < us);
}

/* USER CODE END PFP */

/**
  * @brief  The application entry point.
  * @retval int
  */
int main(void)
{
  /* MCU Configuration--------------------------------------------------------*/

  /* Reset of all peripherals, Initializes the Flash interface and the Systick. */
  HAL_Init();

  /* Configure the system clock */
  SystemClock_Config();

  /* USER CODE BEGIN SysInit */
  HAL_Delay(100);
  service_settings_load();
  settings_load();
  /* USER CODE END SysInit */

  /* Initialize all configured peripherals */
  MX_GPIO_Init();
  MX_DMA_Init();
  MX_I2C1_Init();
  MX_SPI3_Init();
  MX_TIM3_Init();
  MX_TIM17_Init();
  MX_TIM1_Init();
  MX_TIM4_Init();
  /* USER CODE BEGIN 2 */

  // pins check timer
  HAL_TIM_Base_Start_IT(&htim1);
  // us delay timer
  HAL_TIM_Base_Start_IT(&htim4);
  /* USER CODE END 2 */

  /* Infinite loop */
  /* USER CODE BEGIN WHILE */
  main_menu_loop();
  while (1)
  {
    /* USER CODE END WHILE */

    /* USER CODE BEGIN 3 */
  }
  /* USER CODE END 3 */
}

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


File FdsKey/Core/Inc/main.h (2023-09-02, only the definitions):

#define FDSKEY_VERION_MAJOR 1
#define FDSKEY_VERION_MINOR 3
#define FDSKEY_VERION_SUFFIX 0
#define FDS_STOP_MOTOR_Pin GPIO_PIN_2
#define FDS_STOP_MOTOR_GPIO_Port GPIOA
#define FDS_READY_Pin GPIO_PIN_3
#define FDS_READY_GPIO_Port GPIOA
#define FDS_MEDIA_SET_Pin GPIO_PIN_4
#define FDS_MEDIA_SET_GPIO_Port GPIOA
#define FDS_WRITABLE_MEDIA_Pin GPIO_PIN_5
#define FDS_WRITABLE_MEDIA_GPIO_Port GPIOA
#define FDS_READ_DATA_Pin GPIO_PIN_6
#define FDS_READ_DATA_GPIO_Port GPIOA
#define FDS_WRITE_DATA_Pin GPIO_PIN_7
#define FDS_WRITE_DATA_GPIO_Port GPIOA
#define FDS_MOTOR_ON_Pin GPIO_PIN_0
#define FDS_MOTOR_ON_GPIO_Port GPIOB
#define FDS_SCAN_MEDIA_Pin GPIO_PIN_1
#define FDS_SCAN_MEDIA_GPIO_Port GPIOB
#define FDS_SCAN_MEDIA_EXTI_IRQn EXTI0_1_IRQn
#define FDS_WRITE_Pin GPIO_PIN_2
#define FDS_WRITE_GPIO_Port GPIOB
#define FDS_WRITE_EXTI_IRQn EXTI2_3_IRQn
#define BUTTON_DOWN_Pin GPIO_PIN_12
#define BUTTON_DOWN_GPIO_Port GPIOA
#define BUTTON_RIGHT_Pin GPIO_PIN_15
#define BUTTON_RIGHT_GPIO_Port GPIOA
#define BUTTON_LEFT_Pin GPIO_PIN_1
#define BUTTON_LEFT_GPIO_Port GPIOD
#define BUTTON_UP_Pin GPIO_PIN_2
#define BUTTON_UP_GPIO_Port GPIOD
#define SD_DTCT_Pin GPIO_PIN_3
#define SD_DTCT_GPIO_Port GPIOD
#define SD_DTCT_EXTI_IRQn EXTI2_3_IRQn
#define SD_CS_Pin GPIO_PIN_6
#define SD_CS_GPIO_Port GPIOB

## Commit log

2023-03-07 Seems like working prototype
2023-03-07 OLED display library fix
    [fdsemu.c, fdsemu.h, main.c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]
2023-03-07 Updated board, made it longer
2023-03-10 Fonts, new schematic
2023-03-11 DMA writing!
2023-03-12 CRC check, error handling, comments
    [fdsemu.c, fdsemu.h]
2023-03-13 File browser and fixes
    [fdsemu.c, fdsemu.h, main.c]
2023-03-14 Autosave time, button functions
2023-03-15 Splash screens, error handling
    [main.c, splash.c]
2023-03-15 Side selector, OLED fixes
    [main.c, oled.c, splash.c]
2023-03-15 Out of memory error handling
    [main.c]
2023-03-18 Successfully migrated to STM32G0B0CET
2023-03-21 Interrupts fix
2023-03-22 Auto screen off bugfix
    [buttons.c]
2023-03-23 Battery feedback control. Why i need this at all?
2023-03-24 Changed maximum ROM size, fixed size checks, fixed backup restore
    [fdsemu.c, fdsemu.h]
2023-03-24 Removed prototype project
2023-03-25 Error handling, fixed gears image
2023-03-25 Removed unused timers and GPIO from bootloader
2023-04-02 Fixed used space bar
    [fdsemugui.c]
2023-04-03 Schematic update
2023-04-03 PCB update
2023-04-05 Minor service menu fix
    [servicemenu.c]
2023-04-07 PCB changes: labeles and mounting holes
2023-04-07 Support for SD cards with slow SPI
2023-04-08 Fatal error if SD card ejected and more error handling
    [FdsKey.ioc, main.c, main.h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]
2023-04-09 GUI tweaks, button repeat interval tuning
2023-04-10 Direct jump to main menu from subdirectory on back button longpress
2023-04-10 Minor fixes, refactoring, comments
    [settings.c]
2023-04-12 Firmware changed according to the new PCB version
2023-04-13 Support for inverted screen in bootloader
    [main.c]
2023-04-14 PCB rev 1.1.c: smaller holes in pads, moved mounting holes
2023-04-16 Nested brackets
2023-04-16 disable auto loading last state if holding left on power up
2023-04-16 Capacitor photo
2023-04-16 Button model
2023-04-16 Just minor assembly layout update
2023-04-17 Just increased holes size to 1.4mm
2023-04-17 Added gerber files
    [1 - Top.gbr, 2 - Bottom.gbr, BoardOutline.gbr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]
2023-04-17 Added link to gerber files
2023-04-17 Changed hole sizes, again (was too close to PCB edge)
    [1 - Top.gbr, 2 - Bottom.gbr, BottomMask.gbr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]
2023-04-17 Schematic and BOM files
2023-04-17 BoM updated
2023-04-20 Replace STM32 image to match package
2023-04-21 Single button side switch
2023-04-28 Removed autosave delay setting, it's fixed now
    [fdsemu.c, fdsemu.h, settings.c]
2023-05-04 PCB rev1.2: removed holes, moved components a bit
    [1 - Top.gbr, 2 - Bottom.gbr, BottomMask.gbr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]
2023-05-04 Very minor fix
    [1 - Top.gbr, 2 - Bottom.gbr]
2023-05-04 Very minor PCB fix
    [1 - Top.gbr, 2 - Bottom.gbr]
2023-05-04 Case 3D models
    [bottom.stl, buttons.stl, top.stl]
2023-05-04 Critical error when no SD card
    [main.c]
2023-05-04 Fixed FDM 3D models
    [bottom.stl, top.stl]
2023-05-04 Fixed MJF 3D models
    [top.stl]
2023-05-04 Fixed 3D models
    [top.stl]
2023-05-11 Turn on OLED screen on error
    [splash.c]
2023-05-26 Logo on case 3D model
    [top.stl]
2023-05-26 Rotated 3D model
    [top.stl]
2023-06-01 Gerbers update
    [1 - Top.gbr, 2 - Bottom.gbr]
2023-07-18 Extended PCB for 1.5mm for beveling (issue #6)
    [1 - Top.gbr, 2 - Bottom.gbr, BoardOutline.gbr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]
2023-07-20 Button debouncing
2023-07-20 Buttons fix
2023-07-29 MOTOR_ON pin simulation disabled
2023-07-29 SD card detail error codes
    [sdcard.c, sdcard.h, servicemenu.c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]
2023-07-30 Reverted PCB to the version without beveling
    [1 - Top.gbr, 2 - Bottom.gbr, BoardOutline.gbr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]
2023-07-31 SD card compatibility fix
    [sdcard.c]
2023-07-31 FATFS patch applied, On the exFAT volume, new cluster allocation for directory fails with FR_INT_ERR.
    [main.h, servicemenu.c]
2023-08-05 Set MOTOR_ON to push-pull, always high
2023-08-06 Migrated to FatFs R0.15 patch 2, some microSD fixes
    [FdsKey.ioc, FdsKey_bootloader.ioc, blupdater.c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]
2023-08-07 I2C reinit in case of error
    [main.c, splash.c]

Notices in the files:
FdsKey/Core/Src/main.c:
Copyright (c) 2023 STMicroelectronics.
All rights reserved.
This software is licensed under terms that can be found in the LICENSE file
